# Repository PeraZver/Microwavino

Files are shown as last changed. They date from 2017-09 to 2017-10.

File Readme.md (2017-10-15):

# Microwavino

Microwave circuits for makers!

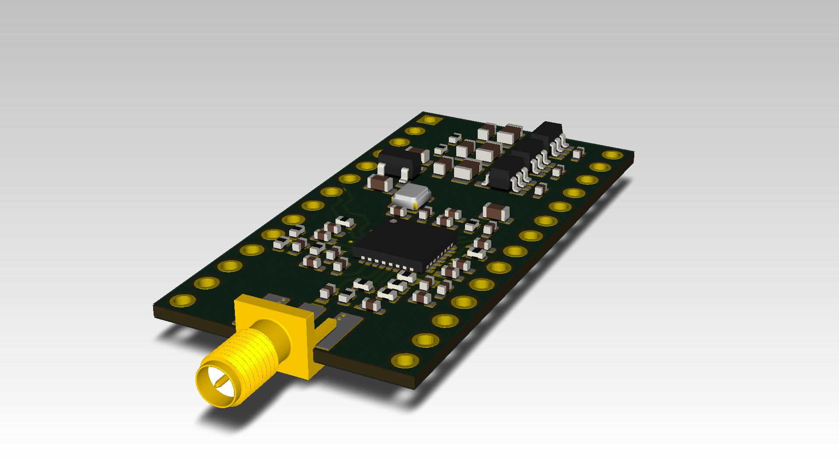
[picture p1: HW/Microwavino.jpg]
Microwavino


Based on  Maxim Integrated PLL chip MAX2871 with integrated VCO. 
Sowftware is based on my previous project [Microwave Transmitter](https://github.com/PeraZver/Microwave-Transmitter).

Pero, September 2017

(https://www.helentronica.com)

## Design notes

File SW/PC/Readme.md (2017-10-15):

# Using python script

Just run it, either from the terminal or from your Python IDE. 
In the code, change proper COM port before the run.

Use following commands:
  * `g` - read MAX2871 register content
  * `rt` - read MAX2871 ADC set to temperature readout
  * `rv` - read MAX2871 ADC set to VCO voltage readout
  * `e` - activate RF output
  * `d` - deactivate RF output
  * `px` - sets the power of RF output, where {x} can be 1,2,3 or 4.

 To change frequency settings, use following commands:
  * `N x` - set integer divider where x is between 16 and 65535.
  * `M x` - set fractional modulus where x is between 2 and 4095.
  * `F x` - set fractional divider where x is between 1 and M.
  * `R x` - set reference divider where x is between 1 and 1023.
  * `D x` - set output divider where x is between 1 and 7.

 Frequency can be easily set by two functions
  * `FINT x` - set sets frequency x in integer mode
  * `FFRAC x` - set sets frequency x in fractional mode

 Special spice is function `sweep`, that enables sweep of every parameter (but will work only with F and N):
  * `sweep x a b dt` - x can be N or F, a is lower limit, b is the upper and dt is time resolution in ms.

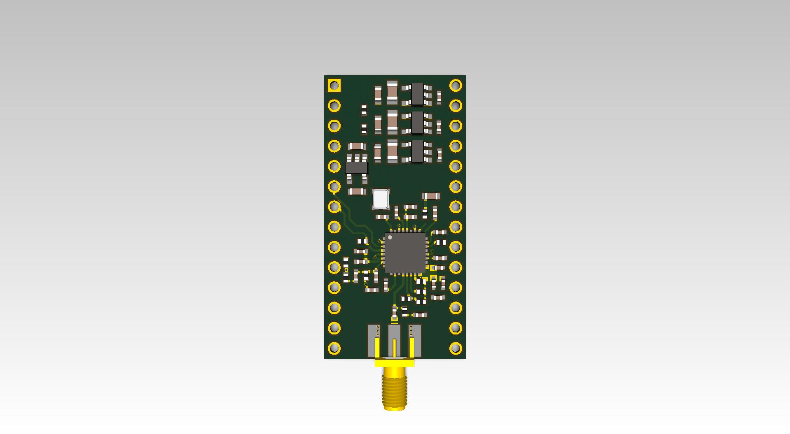
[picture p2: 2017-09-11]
HW/Microwavino_top.jpg

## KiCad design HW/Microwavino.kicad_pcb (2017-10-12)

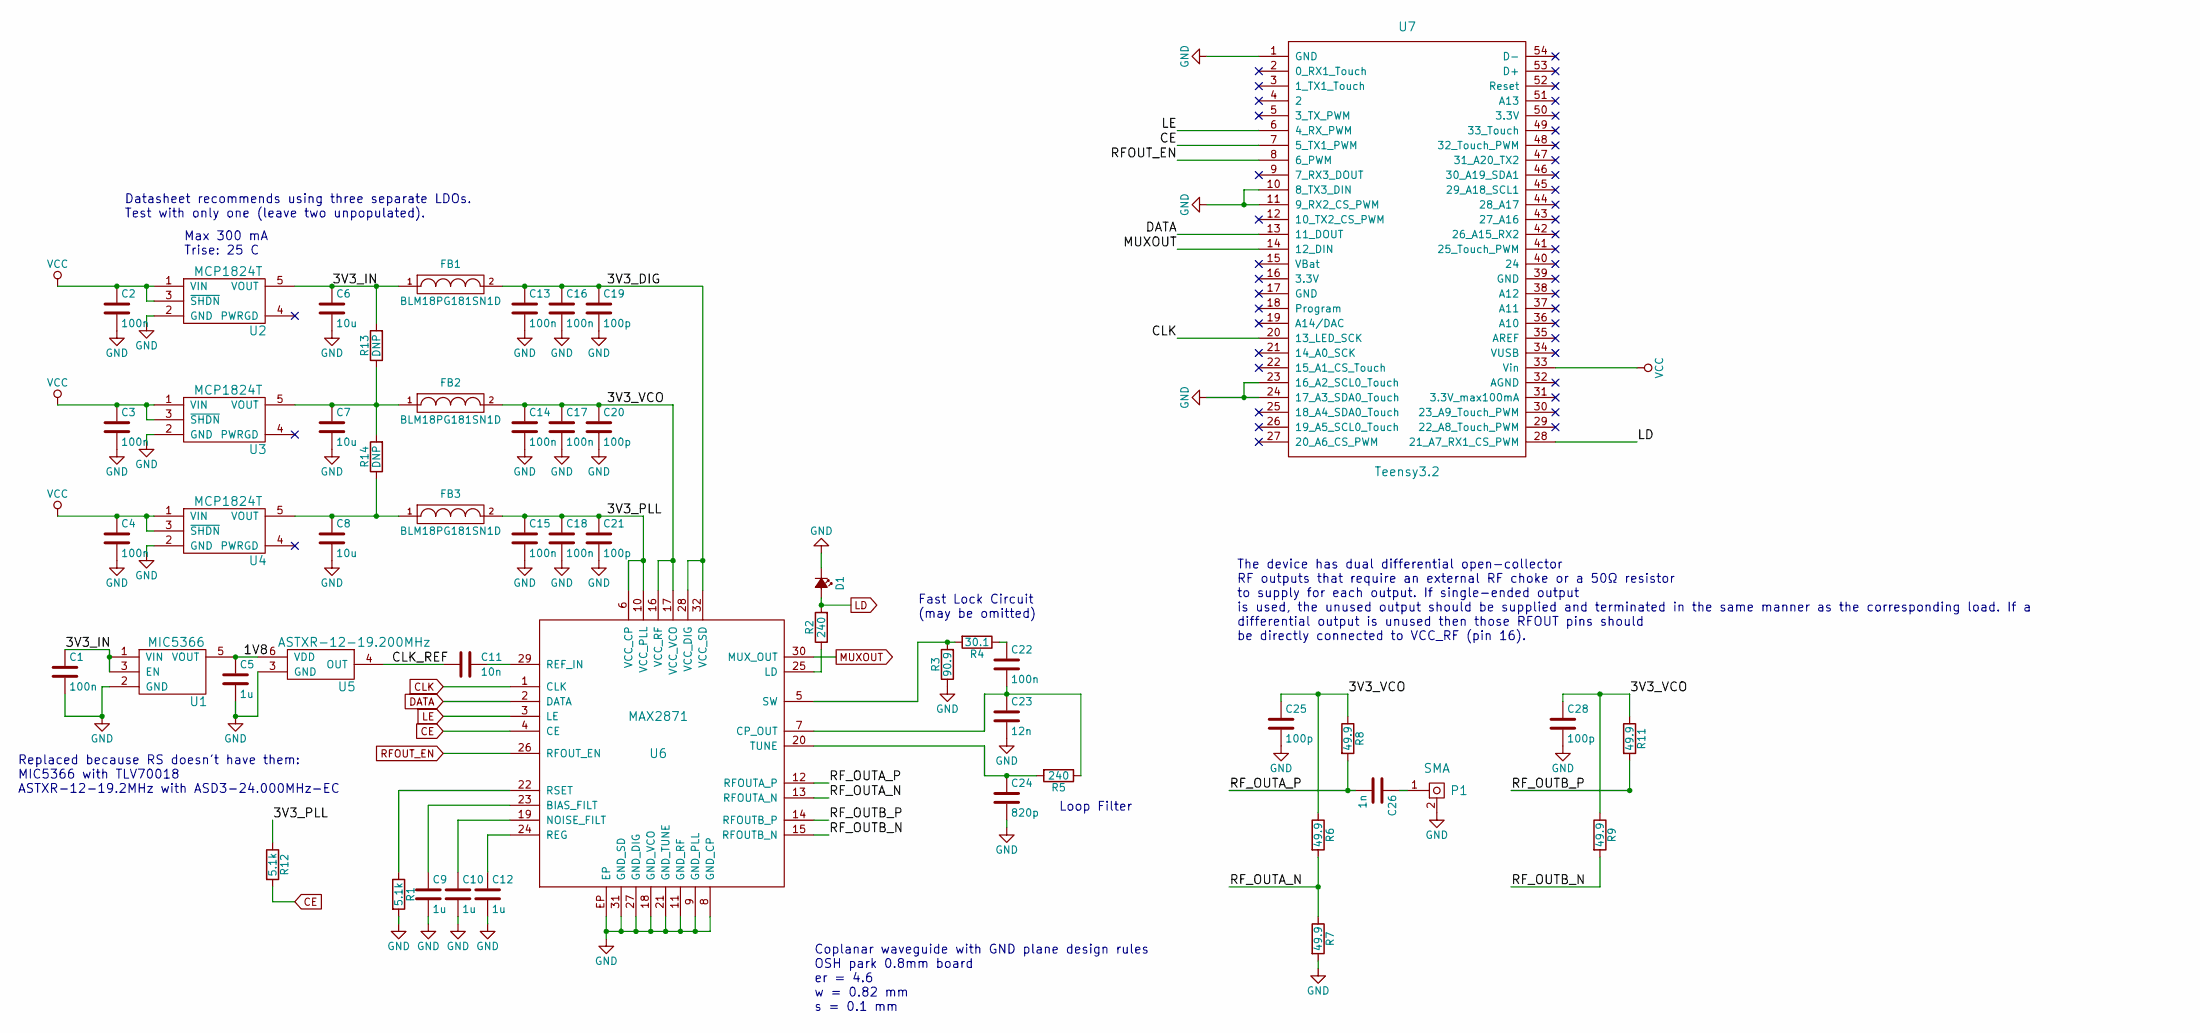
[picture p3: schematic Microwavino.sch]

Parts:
C1: 100n; C_0603b
C2, C3, C4, C13, C14, C15, C16, C17, C18, C22: 100n; C_0402b
C5: 1u; C_0603b
C6, C7, C8: 10u; C_0805b
C9, C10, C12: 1u; C_0402b
C11: 10n; C_0402b
C19, C20, C21, C25, C28: 100p; C_0402b
C23: 12n; C_0402b
C24: 820p; C_0402b
C26: 1n; C_0402b
D1: LED_Small_ALT; LED_0603
FB1, FB2, FB3: BLM18PG181SN1D; C_0603b
P1: SMA; CONSMA003.062
R1, R12: 5.1k; R_0402b
R2, R5: 240; R_0402b
R3: 90.9; R_0402b
R4: 30.1; R_0402b
R6, R7, R8, R9, R11: 49.9; R_0402b
R13, R14: DNP; R_0402b
U1: MIC5366; SOT-353_SC-70-5
U2, U3, U4: MCP1824T; SOT-23-5
U5: ASTXR-12-19.200MHz; ASTRX-12
U6: MAX2871; TQFN-32
U7: Teensy3.2; Teensy30_31_32_LC_modified

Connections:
/1V8: C5.1, U1.5 (VOUT), U5.6 (VDD)
/3V3_DIG: C13.1, C16.1, C19.1, FB1.2, U6.28 (VCC_DIG), U6.32 (VCC_SD)
/3V3_IN: C1.1, C6.1, FB1.1, R13.2, U1.1 (VIN), U1.3 (EN), U2.5 (VOUT)
/3V3_PLL: C15.1, C18.1, C21.1, FB3.2, R12.1, U6.6 (VCC_CP), U6.10 (VCC_PLL)
/3V3_VCO: C14.1, C17.1, C20.1, C25.1, C28.1, FB2.2, R6.1, R8.1, R9.1, R11.1, U6.16 (VCC_RF), U6.17 (VCC_VCO)
/CLK_REF: C11.2, U5.4 (OUT)
/RF_OUTA_N: R6.2, R7.1, U6.13 (RFOUTA_N)
/RF_OUTA_P: C26.2, R8.2, U6.12 (RFOUTA_P)
/RF_OUTB_N: R9.2, U6.15 (RFOUTB_N)
/RF_OUTB_P: R11.2, U6.14 (RFOUTB_P)
CE: R12.2, U6.4 (CE), U7.7 (5_TX1_PWM)
CLK: U6.1 (CLK), U7.20 (13_LED_SCK)
DATA: U6.2 (DATA), U7.13 (11_DOUT)
GND: C1.2, C2.2, C3.2, C4.2, C5.2, C6.2, C7.2, C8.2, C9.2, C10.2, C12.2, C13.2, C14.2, C15.2, C16.2, C17.2, C18.2, C19.2, C20.2, C21.2, C23.2, C24.2, C25.2, C28.2, D1.1 (K), P1.2, R1.2, R3.1, R7.2, U1.2 (GND), U2.2 (GND), U3.2 (GND), U4.2 (GND), U5.3 (GND), U6.8 (GND_CP), U6.9 (GND_PLL), U6.11 (GND_RF), U6.18 (GND_VCO), U6.21 (GND_TUNE), U6.27 (GND_DIG), U6.31 (GND_SD), U6.EP, U7.1 (GND), U7.10 (8_TX3_DIN), U7.11 (9_RX2_CS_PWM), U7.23 (16_A2_SCL0_Touch), U7.24 (17_A3_SDA0_Touch)
LD: D1.2 (A), R2.2, U7.28 (21_A7_RX1_CS_PWM)
LE: U6.3 (LE), U7.6 (4_RX_PWM)
MUXOUT: U6.30 (MUX_OUT), U7.14 (12_DIN)
unnamed: C7.1, FB2.1, R13.1, R14.2, U3.5 (VOUT)
unnamed: C8.1, FB3.1, R14.1, U4.5 (VOUT)
unnamed: C9.1, U6.23 (BIAS_FILT)
unnamed: C10.1, U6.19 (NOISE_FILT)
unnamed: C11.1, U6.29 (REF_IN)
unnamed: C12.1, U6.24 (REG)
unnamed: C22.1, R4.1
unnamed: C22.2, C23.1, R5.1, U6.7 (CP_OUT)
unnamed: C24.1, R5.2, U6.20 (TUNE)
unnamed: C26.1, P1.1
unnamed: R1.1, U6.22 (RSET)
unnamed: R2.1, U6.25 (LD)
unnamed: R3.2, R4.2, U6.5 (SW)
RFOUT_EN: U6.26 (RFOUT_EN), U7.8 (6_PWM)
VCC: C2.1, C3.1, C4.1, U2.1 (VIN), U2.3 (~SHDN), U3.1 (VIN), U3.3 (~SHDN), U4.1 (VIN), U4.3 (~SHDN), U7.33 (Vin)

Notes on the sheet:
Max 300 mA Trise: 25 C
Datasheet recommends using three separate LDOs. Test with only one (leave two unpopulated).
The device has dual differential open-collector RF outputs that require an external RF choke or a 50Ω resistor to supply for each output. If single-ended output is used, the unused output should be supplied and terminated in the same manner as the corresponding load. If a differential output is unu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
Loop Filter
Fast Lock Circuit (may be omitted)
Coplanar waveguide with GND plane design rules OSH park 0.8mm board er = 4.6 w = 0.82 mm s = 0.1 mm
Replaced because RS doesn't have them: MIC5366 with TLV70018 ASTXR-12-19.2MHz with ASD3-24.000MHz-EC

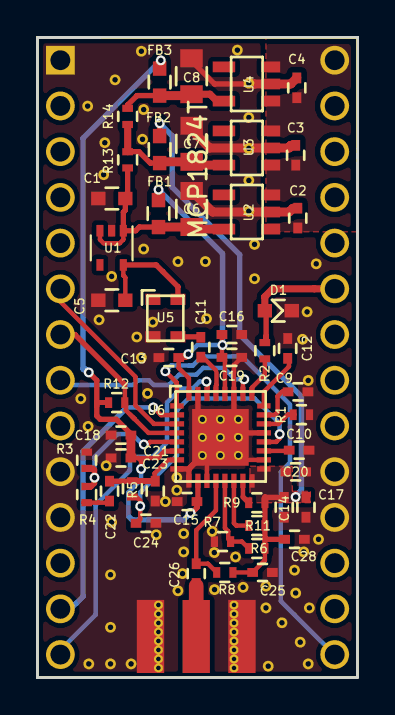
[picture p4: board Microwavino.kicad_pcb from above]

Board: 2 copper layers, 17.8 x 35.6 mm, 52 parts (0 on the bottom side), 32 nets.

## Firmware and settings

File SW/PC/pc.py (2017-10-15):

# -*- coding: utf-8 -*-
#! python
"""
PC Interface with my Microwavino via serial port. 


Created on Wed Sep 06 22:33:43 2017

@author: Helentronica
"""
import serial
import sys
import bitstring as bit
import argparse
#import argparse
#import ast
#import time


f_REF = 24  # Reference frequency
params = {'R':1, 'N':200, 'F':0.0, 'M':100, 'D':5}  # frequency settings parameters
f_PDF = f_REF/params['R'] 


BAUDRATE = 9600
PARITY = False
#Configures serial port
def configure_serial(serial_port):
    return serial.Serial(
        port=serial_port,
        baudrate=BAUDRATE,
        parity=serial.PARITY_EVEN if PARITY else serial.PARITY_NONE,
        stopbits=serial.STOPBITS_TWO,
        bytesize=serial.EIGHTBITS,
        timeout=0.85)
      
def check_frequency (freq_dict):
# Function that calculates frequency based on PLL parameters 
# First test if we're somewhere where it's not allowed to be in   
    global f_PDF 
    if (freq_dict['R'] < 1) | (freq_dict['R'] > 1023):
        print 'R must be between 1 and 1023'
        return 0    
    if (freq_dict['N'] < 16) | (freq_dict['N'] > 65535):
        print 'N must be between 16 and 65535'
        return 0
    if (freq_dict['M'] < 2) | (freq_dict['M'] > 4095):
        print 'M must be between 2 and 4095'
        return 0
    if (freq_dict['F'] > freq_dict['M']):
        print 'F must be lower than M'
        return 0
# Calculate frequency from the given params        
    f_PDF = f_REF/freq_dict['R']
# Now check if N is somewhere where we won't be able to control VCOs.
    N_min = int(round(3000/f_PDF))
    N_max = int(round(6000/f_PDF))
    if ((freq_dict['N'] < N_min) | (freq_dict['N'] > N_max)):
        print 'N must be between '+ str(N_min) + ' and '+ str(N_max)
        return 0
    
    f_VCO = (freq_dict['N'] + freq_dict['F']*1.0/freq_dict['M'])*f_PDF
    f_RFOUT = f_VCO / (2**freq_dict['D'])
    print 'f_PDF is ' + str(round(f_PDF,4)) + ' MHz'
    print 'f_VCO is ' + str(f_VCO) + ' MHz'
    print 'f_RFOUT is ' + str(f_RFOUT) + ' MHz'
    return 1
    

    
def select_D(freq):
#    Selects D parameter based on desired frequency output
    if   3000 < freq <= 6000:
        return 0
    elif 1500 < freq <= 3000:
        return 1
    elif 750  < freq <= 1500:
        return 2    
    elif 375  < freq <= 750:
        return 3    
    elif 187.5 < freq <= 375:
        return 4
    elif 93.75 < freq <= 187.5:
        return 5
    elif 46.875 < freq <= 93.75:
        return 6        
    elif 23.5 < freq <=  46.875:
        return 7
        
def set_frequency_INT(freq):
    # sets  integer mode paramteres for given frequency
    D = select_D(freq) # we need parameter D first
    f_VCO = freq * 2**D  # this is what VCO will need to generate    
    N = int(f_VCO/f_PDF)
    return N, D

def set_frequency_FRAC(freq):
    # sets  integer mode paramteres for given frequency
    D = select_D(freq) # we need parameter D first
    f_VCO = freq * 2**D  # this is what VCO will need to generate    
    N = int(f_VCO/f_PDF)
    F = int((f_VCO/f_PDF - N)*params['M'])
    return N, D, F


def set_param_sweep(args):
#    returns command that starts given parameter sweep
    param = args[1]
    start = args[2]
    stop  = args[3]
    if (len(args) == 5):
        td = args[4]
    else:
        td = '10'    
    return ('s'+ param + start + 'a'+ stop +'a' + td +'a')
    
def freq_sweep(f_start, f_stop):
#    set frequency sweep from f_start to f_stop
    N_start, D_start = set_frequency_INT(f_start)
    N_stop, D_stop = set_frequency_INT(f_stop)
    return (set_param_sweep(('sweep','N', str(N_start), str(N_stop))))

        
def read_registers(ser):
# Reads and parses registers from MAX2871
    ser.write('g')
    while(True):
        line = ser.readline().strip()
        if line == 'MAX2871 Registers printout:':
            break
    print line
    for i in range(0,6):
        line = ser.readline()
        print 'Register ' + str(i)
        parse_register(line.strip(), i)
        print ' '
#    Update paramters that set frequency            
    check_frequency(params)

def parse_register(line, i):
#parses each register and displays values in human form  
        # if register has first bits equal to 0, Teensy will 
        # send data without them. That's why I fill like this
        while (len(line) < 8): 
            line = '0'+line
        print line
        reg = bit.BitArray(hex=line)
        #examine registers
        if (i == 0):
            print 'Integer mode: ' + str(reg[0])
            print 'Integer divider N: ' + str(reg[1:17].uint)
            print 'Fraction divider F: ' + str(reg[17:29].uint)
            params['N'] = reg[1:17].uint
            params['F'] = reg[17:29].uint
            
        elif (i == 1):
            print 'Fraction Modulus M: ' + str(reg[17:29].uint)
            params['M'] = reg[17:29].uint
            
        elif (i == 2):
            print 'Reference divider R: ' + str(reg[8:18].uint)
            print 'Reference DBR: ' + str(reg[6])
            print 'Reference DIV2: ' + str(reg[7])
            params['R'] = reg[8:18].uint
            
        elif (i == 4):
            print 'Output divider DIVA: ' + str(reg[9:12].uint)
            print 'Output power RFOUTA: ' + str(3*reg[27:29].uint - 4) + ' dBm'
            print 'Output power RFOUTA: ' + str(3*reg[24:26].uint - 4) + ' dBm'
            print 'RFOUTA enabled: ' + str(reg[26])
            print 'RFOUTB enabled: ' + str(reg[23])
            params['D'] = reg[9:12].uint

    
def command_parser(data, ser):
# function that converts user input to Teensy commands
    user_in = data.split(' ');

    if user_in[0] in ['N', 'F', 'M', 'R']:
        params[user_in[0]] = int(user_in[1])
        check_frequency(params)  # update frequecy settings
        return (user_in[0]+user_in[1]+'a')
            
    elif (user_in[0] == 'D'):
        params['D'] = int(user_in[1])
        check_frequency(params)
        return ('D'+user_in[1])
        
    elif (user_in[0] in ("sweep", "SWEEP")):
        return set_param_sweep(user_in)
        
    elif (user_in[0] == 'g'):
        read_registers(ser)
        return ('')
    
    elif (user_in[0] == 'FINT'):  # Set frequency in integer mode
        N, D = set_frequency_INT(int(user_in[1]))
        ser.write('D'+str(D))
        ser.write('N'+str(N)+'a')
        ser.write('F0a')  # Kill fractional mode
        for i in range(1,6):
            line = ser.readline()
            if  line.strip():  # evaluates to true when an "empty" line is received
                print line.strip()
        return ('')
        
    elif (user_in[0] == 'FFRAC'):  # Set frequency in fractional mode
        N, D, F = set_frequency_FRAC(float(user_in[1]))
        ser.write('D'+str(D))
        ser.write('N'+str(N)+'a')
        ser.write('F'+str(F)+'a')        
        for i in range(1,6):
            line = ser.readline()
            if  (line.strip() != ''):
                print line.strip()
        return ('') 
        
    elif (user_in[0] == 'help'):
        read_help(user_in)
        return('')
        
    else:
        return data
        
        
        
    
    
def main():
    parser = argparse.ArgumentParser(description="Microwavino Python Interface")
    print "Microwavino Interface"
    print "v1.1"
    print "type 'help [command]' if not sure how to proceed\n"
    print "Pero, September 2017"
    parser.add_argument('port',metavar='Port', help='Serial port')
    args = parser.parse_args()
    
    if len(sys.argv)<2:
        print "Give serial port address as a command line argument."
        exit()
    
    try:
        ser = configure_serial(args.port)
        if not ser.isOpen():
            raise Exception
        else:
            print "\nSerial port opened"
            print "Initializing Microwave transmitter...\n"
            ser.write(' ')
    except:
        print 'Opening serial port failed'
        exit(1)    
        
    while True:
        try:
            line = ser.readline()
            if not line.strip():  # evaluates to true when an "empty" line is received
                var = raw_input(">> ")
                if var:
                    ser.write(command_parser(var, ser))

            else:
                print line.strip()
            
        except KeyboardInterrupt:
            ser.close()
            sys.exit(1)
            break

    
def read_help(*args):
# displays help for each command
    if (len(args[0]) > 1):
        command = args[0][1]
    else:
        command = args[0][0]

    if (command == 'D'):
        print """ 
        Output frequency divider (DIVA):
        0 = Divide by 1, if 3000MHz ≤ fRFOUTA ≤ 6000MHz
        1 = Divide by 2, if 1500MHz ≤ fRFOUTA< 3000MHz
        2 = Divide by 4, if 750MHz ≤ fRFOUTA < 1500MHz
        3 = Divide by 8, if 375MHz ≤ fRFOUTA < 750MHz
        4 = Divide by 16, if 187.5MHz ≤ fRFOUTA < 375MHz
        5 = Divide by 32, if 93.75MHz ≤ fRFOUTA < 187.5MHz
        6 = Divide by 64, if 46.875MHz ≤ fRFOUTA < 93.75MHz
        7 = Divide by 128, if 23.5MHz ≤ fRFOUTA< 46.875MHz"""
        
    elif (command == 'sweep'):
        print """ 
        function SWEEP X a b [dt]
        sweeps parameter X from a to b with resolution of dt milliseconds. 
        Default value for dt is 10 ms. """
    
    elif (command == 'g'):
        print """ 
        command g displays current content of registers 0 - 5 of MAX2871."""
        
    elif (command == 'r'):
        print """
        Readout of MAX2871 register 6. Internal ADC of MAX2871 can be configured
        to measure temperature or voltage at the VCO:
        rt - display temperature value.
        rv - display VCO voltage. """
    
    else:
        print """ 
        COMMAND LIST:
        -----------------------------------------------
        g - read MAX2871 register content
        rt - read MAX2871 ADC set to temperature readout
        rv - read MAX2871 ADC set to VCO voltage readout
        e - activate RF output
        d - deactivate RF output
        px - sets the power of RF output, where {x} can be 1,2,3 or 4.
        
        To change frequency settings, use following commands:
        
        N x - set integer divider where x is between 16 and 65535.
        M x - set fractional modulus where x is between 2 and 4095.
        F x - set fractional divider where x is between 1 and M.
        R x - set reference divider where x is between 1 and 1023.
        D x - set output divider where x is between 1 and 7.
        
        To change frequency directly, use two functions:
        
        FINT x - set frequency x in integer mode
        FFRAC x - set frequency x in fractional mode
        
        To sweep parameters, try this:
        
        sweep x a b dt - sweep parameters from a to b."""        
        
if __name__ == "__main__":   
    main()

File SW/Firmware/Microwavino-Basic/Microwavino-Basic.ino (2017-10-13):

#include <Arduino.h>

/*  Basic Microwavino configuration and test
 *
 *  This example configures sinthesyzer MAX2871 over SPI.
 *  CLK is pin 13
 * DATA IN (MISO) is pin 12
 * DATA OUT (MOSI) is pin 11
 * LE (SS) for MAX2871 is pin 5
 * CE for MAX2871 is pin 4
 * RF EN is pin 7

Pero, September 2017

*/
#include <SPI.h>
#include "MAX2871.h"

// user input
char incomingChar = 0;  //Serial input

// sweep parameters
uint16_t a, b, dt;
char divider_type;

//fractional mode flag
boolean frac = 0;

//functiondeclarations
uint16_t String2Int();

void setup() {
  Serial.begin(9600);
  while (!Serial.available()) ;
  Serial.println("Microwavino");
  Serial.println("Basic configuration example");
  Serial.println("v1.0");
  Serial.println("Pero, September 2017");
  Serial.println(" ");
  Serial.println(" ");

  // initialize SPI:
  SPI.begin();
  Serial.println("SPI Initialized");

  MAX2871_Init ();
  Serial.println("MAX2871 Initialized");
}

void loop() {
  if(Serial.available() > 0){
    incomingChar = Serial.read();

    switch (incomingChar){


      case 'e':
         MAX2871_RFA_Enable();
         Serial.println("RFA out activated.");
         break;

      case 'd':
         MAX2871_RFA_Disable();
         Serial.println("RFA out deactivated.");
         break;

      case 'r':
         MAX2871_Read(Serial.read());   // type t for temperature or v for VCO tuning voltage
         break;

      case 'g':
         Serial.println("MAX2871 Registers printout:");
         MAX2871_Print_Registers();
         break;

      case 'p':
          MAX2871_RFA_SelectPower(Serial.read());
          break;

      case 'D':
          //Serial.print("Set output divider value DIVA (0-7): ");
          MAX2871_SetDIVA(Serial.read());
          break;

      case 'N':
          //Serial.print("Set integer division value N: ");
          MAX2871_SetN(String2Int());
          break;

      case 'F':
          //Serial.println("Fractional mode selected!");
          if(!frac)
            frac = 1;
            MAX2871_SetFracMode();
          //Serial.print("Set fractional division value F: ");
          MAX2871_SetF(String2Int());
          break;

      case 'R':
          //Serial.print("Set reference divider value R: ");
          MAX2871_SetR(String2Int());
          break;

      case 'M':
          //Serial.print("Set modulus division value M: ");
          MAX2871_SetM(String2Int());
          break;

      case 's':
          divider_type = Serial.read();  // N or F
          a = String2Int();   // lower limit
          b = String2Int();   // upper limit
          dt = String2Int();  //time delay
          Serial.println("Frequency Sweep activated.");
          Serial.print(divider_type);
          Serial.print(" from ");
          Serial.print(a);
          Serial.print(" to ");
          Serial.print(b);
          Serial.print(" in steps of ");
          Serial.print(dt);
          Serial.println(" ms.");
          MAX2871_Sweep(divider_type, a, b, dt);
          break;

      default:
            ;
    }
  }

  delay(1000);
}

uint16_t String2Int(){
  /* converts stream of serial input characters to integer.
     Condition is that stream ends with 'a'. */
  uint16_t number = 0;
  char a = '0';
  while (a != 'a'){
    if(Serial.available()){
      a = Serial.read();
      // Serial.print("\nRead character: ");
    //  Serial.print(a, DEC);
      if (a != 'a')
          number = number*10 + (a - 48);  // in ascii '0' is 48 dec.
    }
  }
  return number;
}

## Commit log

2017-09-06 init commit
    [Microwavino.kicad_pcb, Microwavino.sch]
2017-09-07 testing connection
    [Microwavino.sch]
2017-09-07 prelim placement
    [Microwavino.sch]
2017-09-07 before placement
    [Microwavino.sch]
2017-09-08 prelim layout
    [Microwavino.kicad_pcb, Microwavino.sch]
2017-09-08 route all except power
    [Microwavino.kicad_pcb, Microwavino.sch]
2017-09-11 layout completed v1.0
    [Microwavino.kicad_pcb, Microwavino.sch]
2017-09-11 rm teensy folders
2017-09-11 drc pass
    [Microwavino.kicad_pcb, Microwavino.sch]
2017-09-11 added footprint SOT-323-70-sc-5
    [Microwavino.kicad_pcb, Microwavino.sch]
2017-09-12 released and ordered
    [Microwavino.kicad_pcb]
2017-10-12 added sw and wiki
    [Microwavino.kicad_pcb, Microwavino.sch]
2017-10-13 back to arduino
2017-10-15 fixed error, modified script
    [MAX2871.h, pc.py]
